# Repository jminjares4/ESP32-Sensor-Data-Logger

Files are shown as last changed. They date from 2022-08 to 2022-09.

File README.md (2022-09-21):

# ESP32-Sensor-Data-Logger

<div align='center'>






</div>

## **Hardware**
sensor data logger gif

## **Mechanical**
housing
* The housing was developed by [Rogelio Marco](https://github.com/RogelioMarco) :gear:.

## **Development**
|Microcontroller|Software|Enviroment|Operating System|
| :---| :---| :---| :---|
|  | |  | |

## **Author**
* [**Jesus Minjares** :zap:](https://github.com/jminjares4)<br>
  * Master of Science in Computer Engineering<br>
 


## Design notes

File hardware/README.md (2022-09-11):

# Hardware

The hardware was developed through [KiCad](https://www.kicad.org) 6.0. 

## **Development**


## **Features**
- [x] USB-C Battery Charger
  - [x] 1.72 A max current charge
  - [x] Load protection
  - [x] Reverse current protection
- [x] Battery voltage reading 
- [x] MicroSD Card
  - [x] ESD Protection
- [x] Real-Time Clock 
  - [x] External power supply (CR2032)
- [x] External UART to flash ESP32 
- [x] I2C and Analog pins
- [x] Onboard status LEDs 
- [x] Testpoint
  - [x] 3.3V
  - [x] Vbat
  - [x] Ground

## **Schematic**
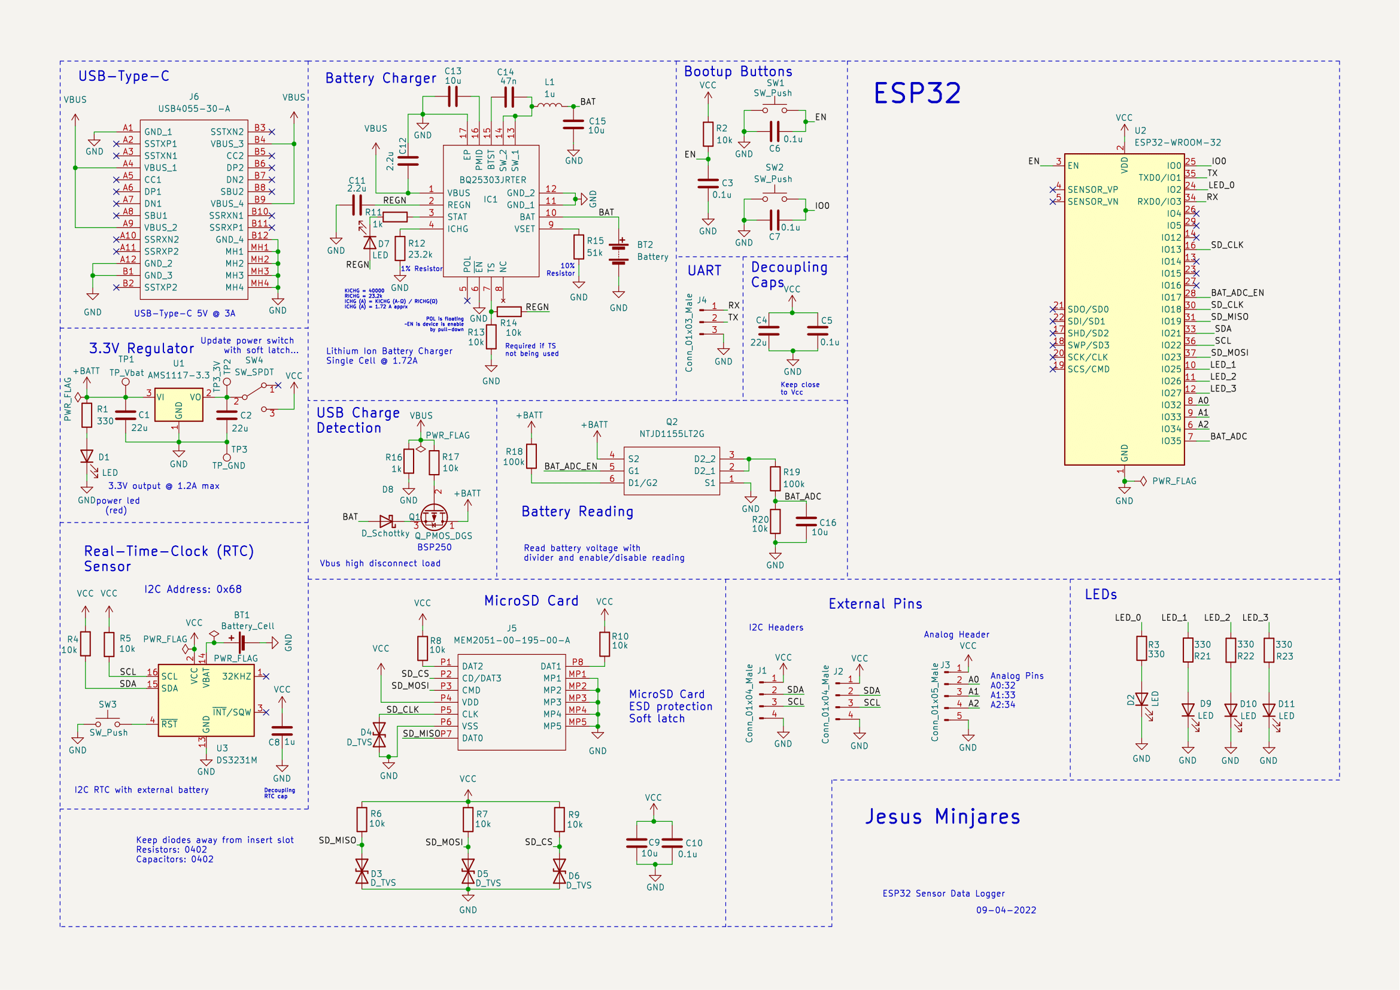
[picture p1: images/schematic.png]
hardware schematic


## **Printed Circuit Board**
### Front View
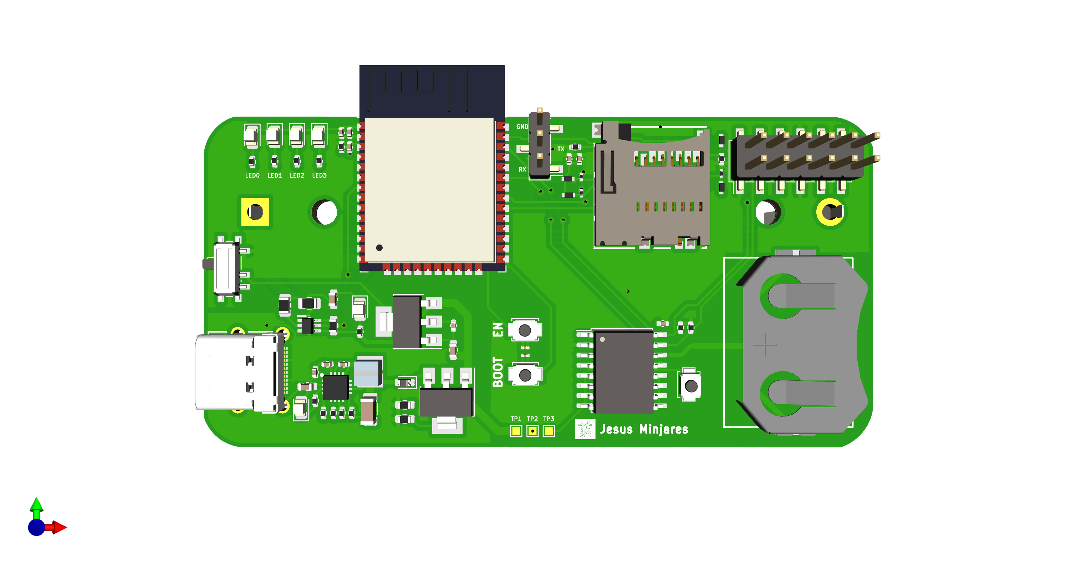
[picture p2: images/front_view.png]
front_view

### Back View
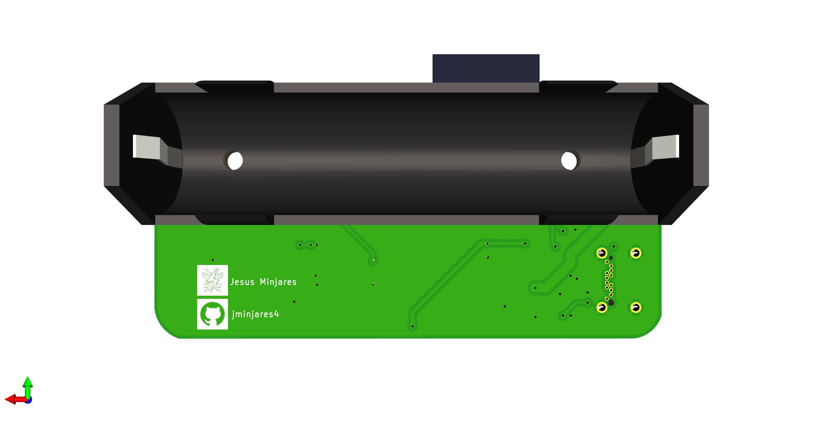
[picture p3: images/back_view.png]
back_view


## **Author**
* [**Jesus Minjares** :zap:](https://github.com/jminjares4)<br>
  * Master of Science in Computer Engineering<br>
 


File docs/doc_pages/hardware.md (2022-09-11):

# Hardware

The hardware was developed through [KiCad](https://www.kicad.org) 6.0. 

## Development


## Features
- [✓] USB-C Battery Charger
  - [✓] 1.72 A max current charge
  - [✓] Load protection
  - [✓] Reverse current protection
- [✓] Battery voltage reading 
- [✓] MicroSD Card
  - [✓] ESD Protection
- [✓] Real-Time Clock 
  - [✓] External power supply (CR2032)
- [✓] External UART to flash ESP32 
- [✓] I2C and Analog pins
- [✓] Onboard status LEDs 
- [✓] Testpoint
  - [✓] 3.3V 
  - [✓] Vbat
  - [✓] Ground

## Schematic
hardware schematic

## Printed Circuit Board
### Front View
front_view
### Back View
back_view

## Author
* [**Jesus Minjares**](https://github.com/jminjares4)<br>
  * Master of Science in Computer Engineering<br>
 


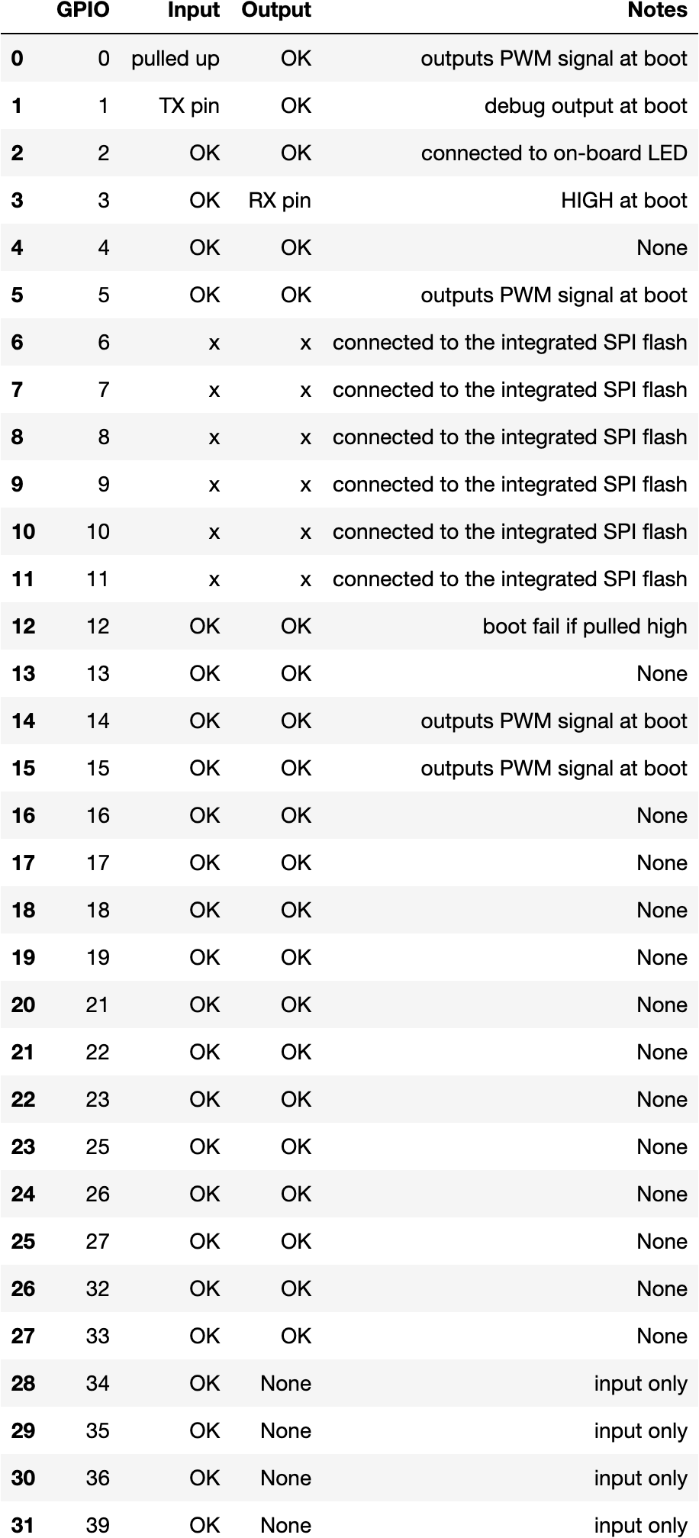
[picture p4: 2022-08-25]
images/esp_pinout.png

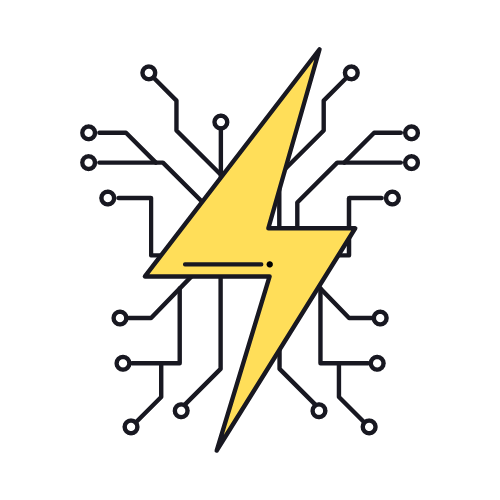
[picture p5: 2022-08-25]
images/jminjares4.png

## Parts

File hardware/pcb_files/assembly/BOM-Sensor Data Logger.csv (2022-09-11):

Comment | Designator | Footprint | LCSC
100k | R18 | R_0603_1608Metric
D_TVS | D3 | TPD1E10B06DPYR
10u | C16 | C_0603_1608Metric
330 | R1 | R_0402_1005Metric
AMS1117-3.3 | U1 | SOT-223-3_TabPin2
10k | R6 | R_0201_0603Metric
D_TVS | D5 | TPD1E10B06DPYR
0.1u | C6 | C_0201_0603Metric
SW_SPDT | SW4 | SW_SPDT_PCM12
LED | D10 | LED_0805_2012Metric
330 | R21 | R_0402_1005Metric
1k | R11 | R_0402_1005Metric
TP_Vbat | TP1 | TestPoint_Pad_1.0x1.0mm
Conn_01x12_Male | J1 | PinHeader_2x06_P2.54mm_Vertical_SMD
SW_Push | SW2 | SW_SPST_B3U-1000P
D_TVS | D4 | TPD1E10B06DPYR
23.2k | R12 | R_0402_1005Metric
10u | C9 | C_0402_1005Metric
10k | R4 | R_0402_1005Metric
10k | R13 | R_0402_1005Metric
USB4055-30-A | J6 | USB405530A
1u | C8 | C_0402_1005Metric
TP3_3V | TP2 | TestPoint_Pad_1.0x1.0mm
0.1u | C5 | C_0402_1005Metric
10k | R7 | R_0201_0603Metric
330 | R23 | R_0402_1005Metric
MEM2051-00-195-00-A | J5 | MEM20510019500A
10k | R8 | R_0402_1005Metric
51k | R15 | R_0402_1005Metric
Battery_Cell | BT1 | 3034
2.2u | C11 | C_0603_1608Metric
SW_Push | SW3 | SW_SPST_B3U-1000P
ESP32-WROOM-32 | U2 | ESP32-WROOM-32
22u | C2 | C_0402_1005Metric
330 | R3 | R_0402_1005Metric
NTJD1155LT2G | Q2 | SOT65P210X110-6N
22u | C4 | C_0402_1005Metric
0.1u | C7 | C_0201_0603Metric
D_TVS | D6 | TPD1E10B06DPYR
10k | R20 | R_0805_2012Metric
LED | D9 | LED_0805_2012Metric
Q_PMOS_DGS | Q1 | SOT-223-3_TabPin2
LED | D7 | LED_0805_2012Metric
1k | R16 | R_0603_1608Metric
BQ25303JRTER | IC1 | QFN50P300X300X80-17N-D
LED | D2 | LED_0805_2012Metric
100k | R19 | R_0805_2012Metric
LED | D11 | LED_0805_2012Metric
0.1u | C10 | C_0402_1005Metric
330 | R22 | R_0402_1005Metric
10u | C15 | C_1206_3216Metric
SW_Push | SW1 | SW_SPST_B3U-1000P
10k | R10 | R_0402_1005Metric
10k | R14 | R_0402_1005Metric
10k | R5 | R_0402_1005Metric
Conn_01x03_Male | J4 | PinHeader_1x03_P2.54mm_Vertical_SMD_Pin1Left
D_Schottky | D8 | D_0603_1608Metric
10u | C13 | C_0402_1005Metric
1u | L1 | INDC3030X200N
LED | D1 | LED_0805_2012Metric
TP_GND | TP3 | TestPoint_Pad_1.0x1.0mm
10k | R17 | R_0603_1608Metric
DS3231M | U3 | SOIC-16W_7.5x10.3mm_P1.27mm
0.1u | C3 | C_0402_1005Metric
22u | C1 | C_0603_1608Metric
2.2u | C12 | C_0402_1005Metric
47n | C14 | C_0402_1005Metric
10k | R9 | R_0201_0603Metric
10k | R2 | R_0402_1005Metric
Battery | BT2 | BatteryHolder_MPD_BH-18650-PC2

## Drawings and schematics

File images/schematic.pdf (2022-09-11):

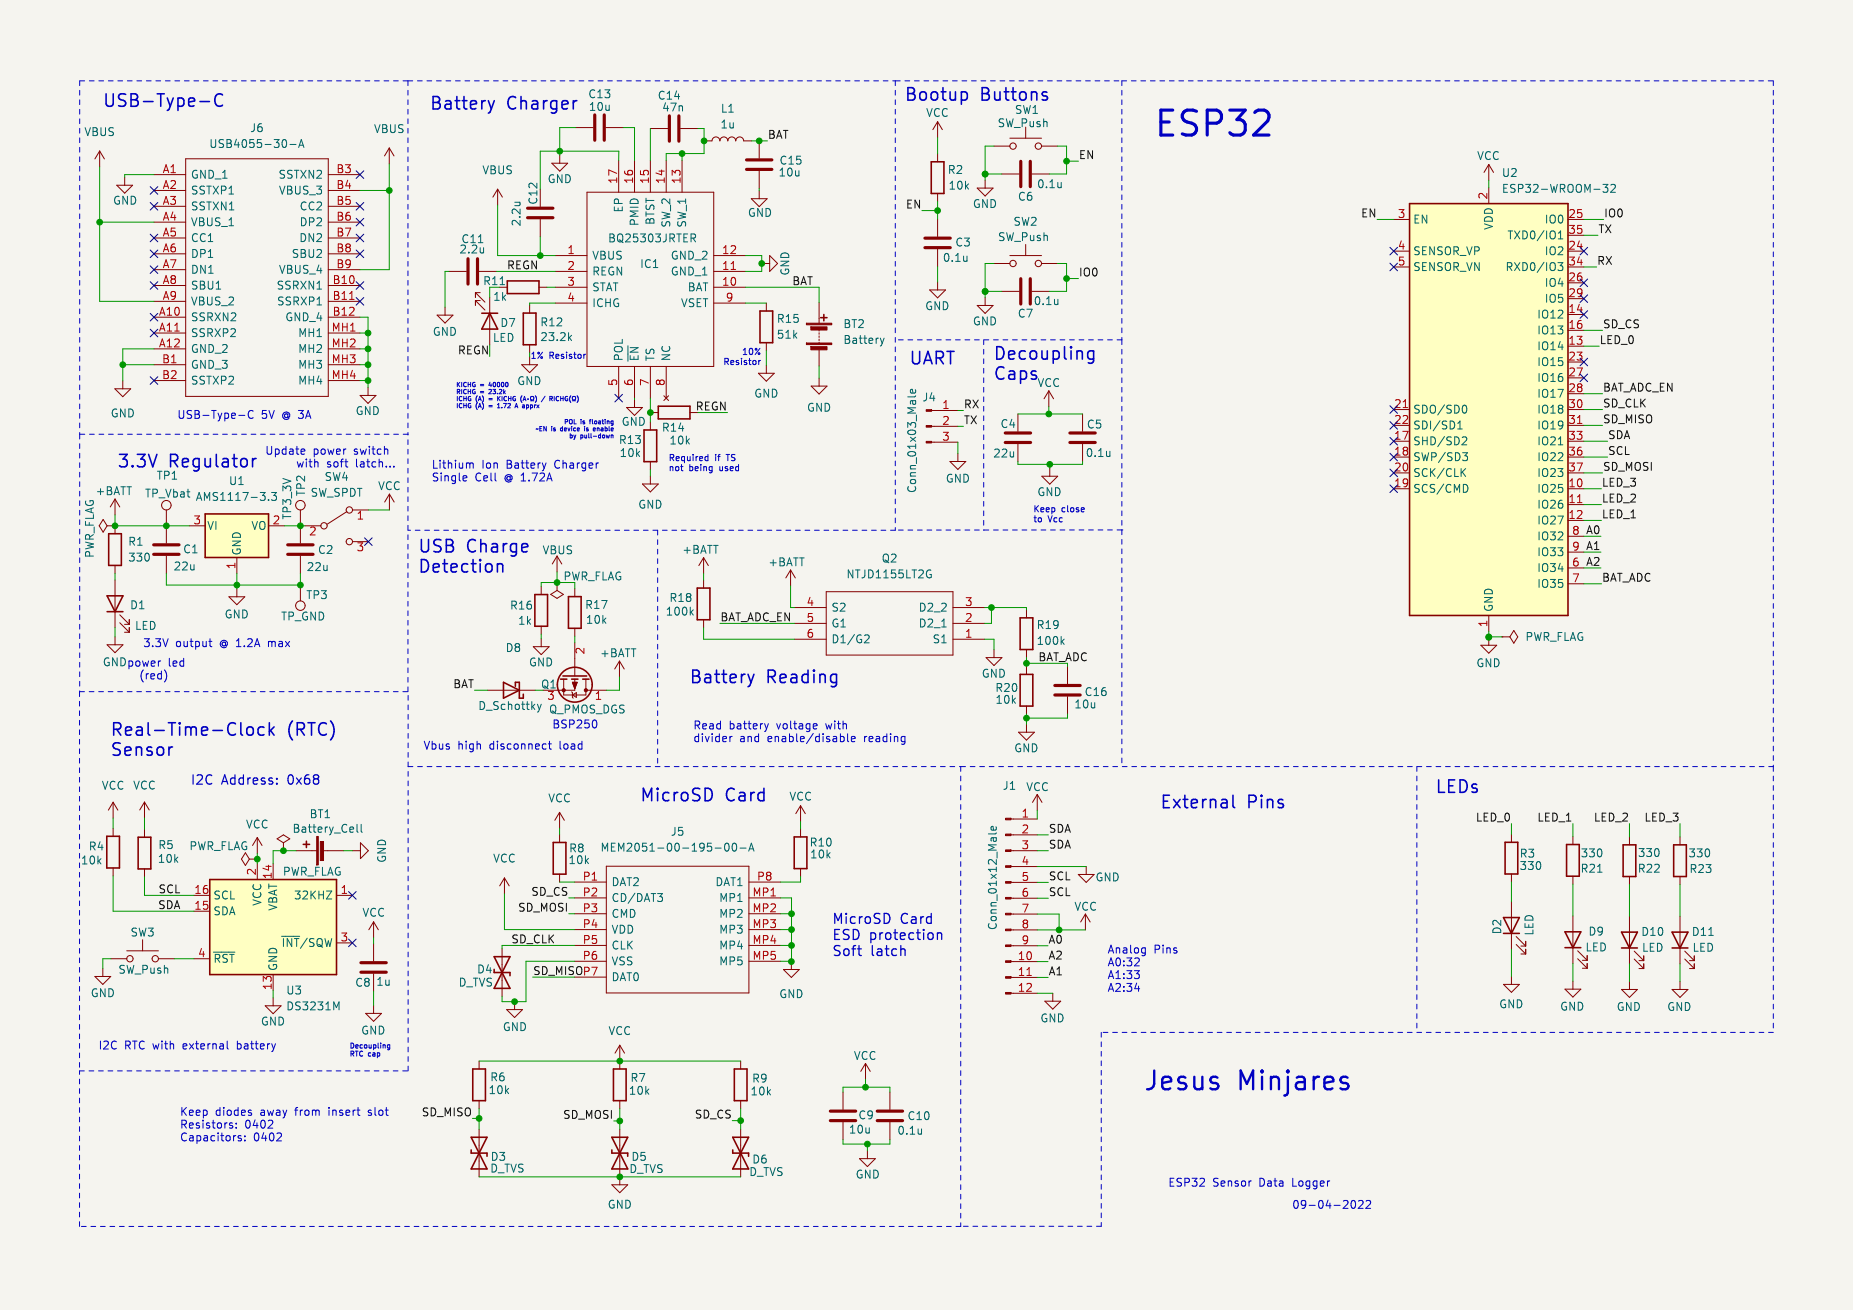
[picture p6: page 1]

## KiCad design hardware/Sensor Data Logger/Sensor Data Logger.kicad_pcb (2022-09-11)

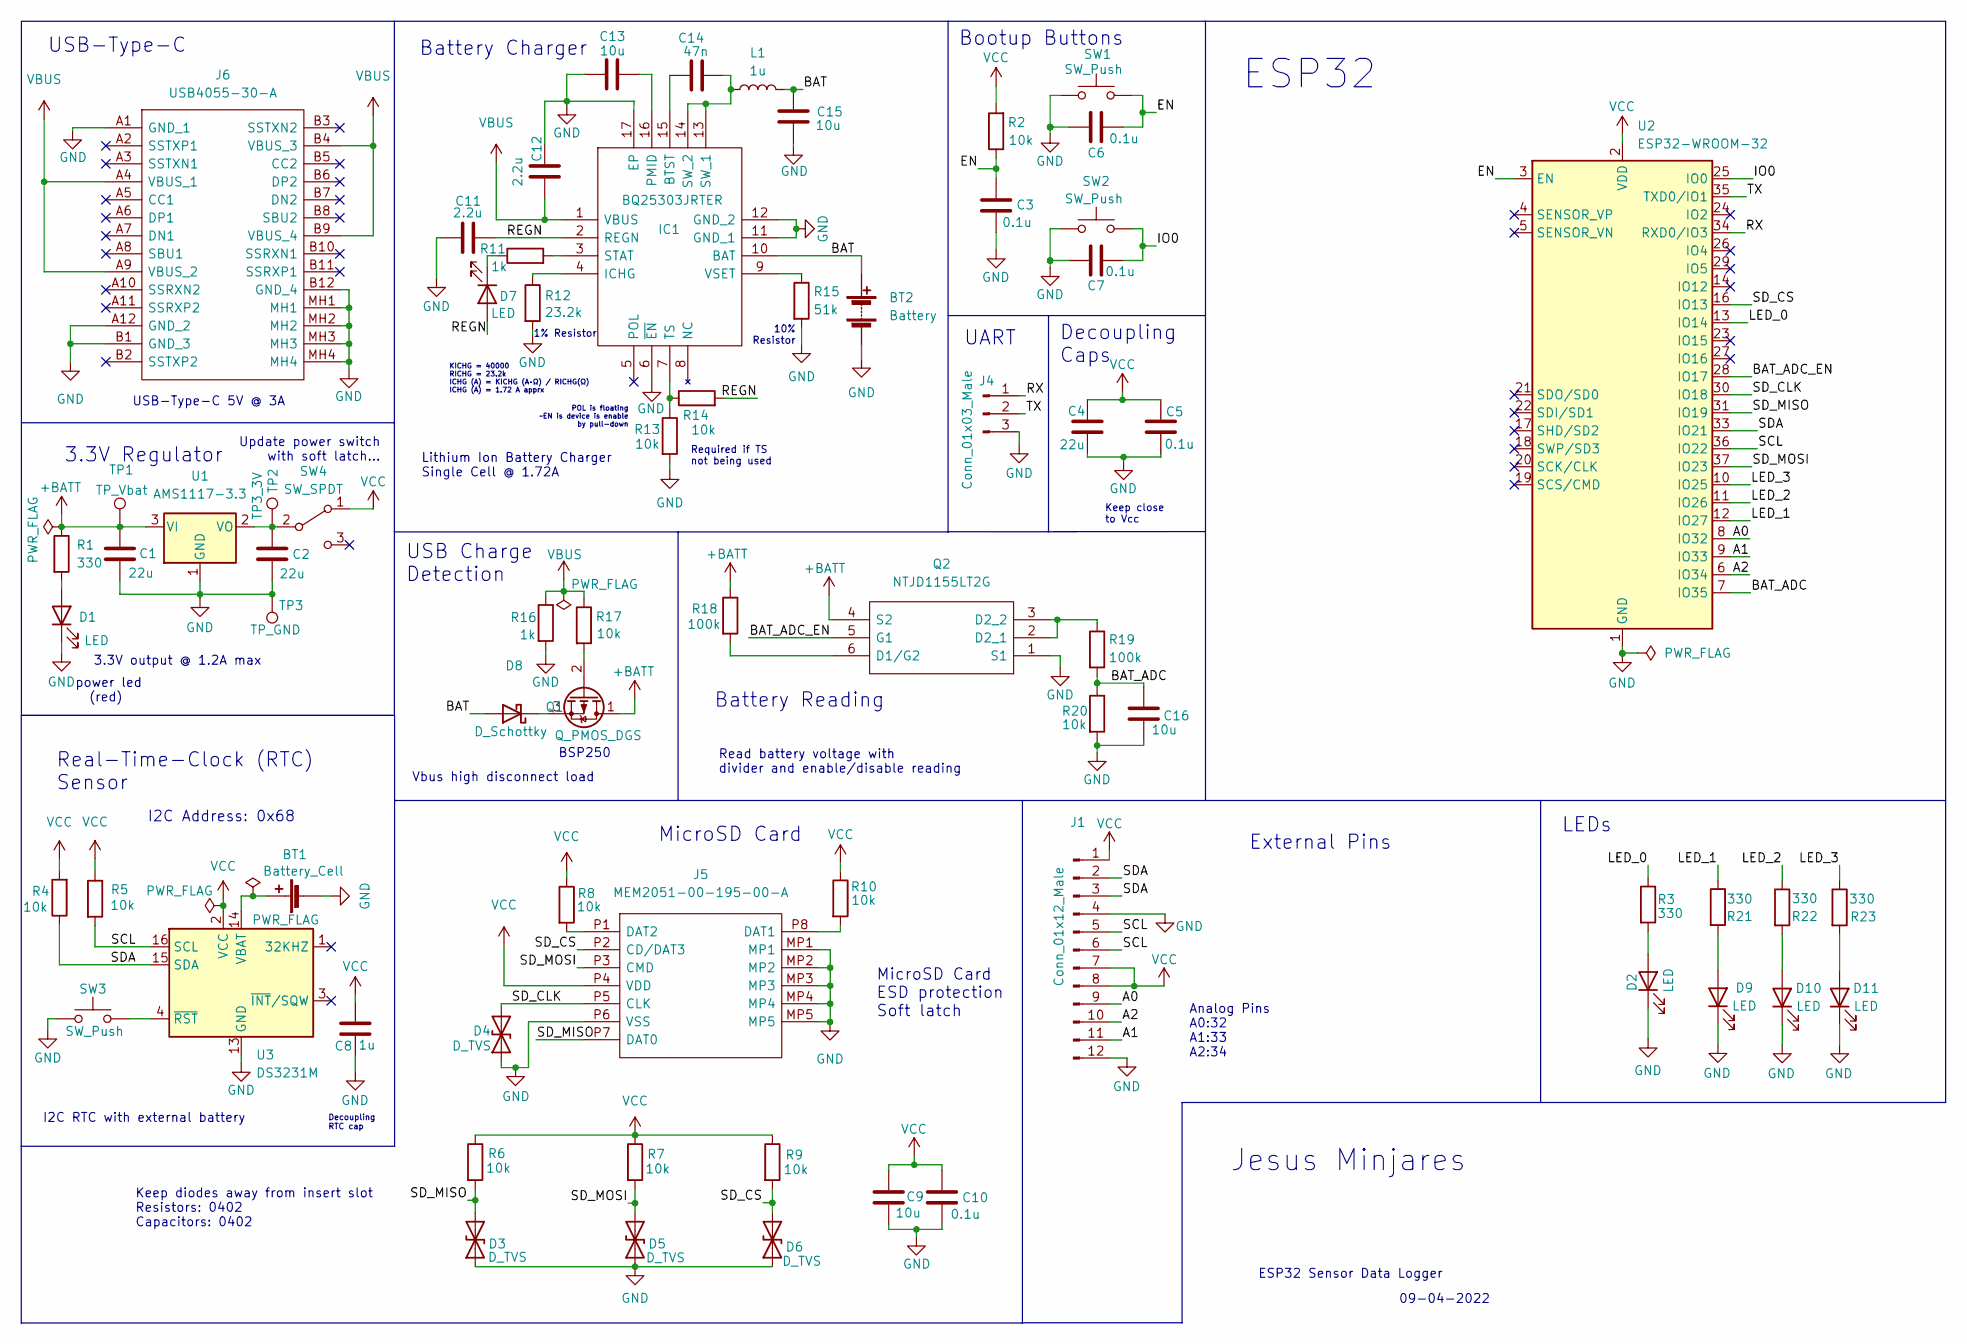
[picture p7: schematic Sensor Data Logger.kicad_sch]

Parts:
BT1: Battery_Cell; 3034
BT2: Battery; BatteryHolder_MPD_BH-18650-PC2
C1: 22u; C_0603_1608Metric
C2, C4: 22u; C_0402_1005Metric
C3, C5, C10: 0.1u; C_0402_1005Metric
C6, C7: 0.1u; C_0201_0603Metric
C8: 1u; C_0402_1005Metric
C9, C13: 10u; C_0402_1005Metric
C11: 2.2u; C_0603_1608Metric
C12: 2.2u; C_0402_1005Metric
C14: 47n; C_0402_1005Metric
C15: 10u; C_1206_3216Metric
C16: 10u; C_0603_1608Metric
D1, D2, D7, D9, D10, D11: LED; LED_0805_2012Metric
D3, D4, D5, D6: D_TVS; TPD1E10B06DPYR
D8: D_Schottky; D_0603_1608Metric
IC1: BQ25303JRTER; QFN50P300X300X80-17N-D; Manufacturer_Part_Number BQ25303JRTER; Mouser Part Number 595-BQ25303JRTER
J1: Conn_01x12_Male; PinHeader_2x06_P2.54mm_Vertical_SMD
J4: Conn_01x03_Male; PinHeader_1x03_P2.54mm_Vertical_SMD_Pin1Left
J5: MEM2051-00-195-00-A; MEM20510019500A; Manufacturer_Part_Number MEM2051-00-195-00-A; Mouser Part Number 640-MEM20510019500A
J6: USB4055-30-A; USB405530A; Manufacturer_Part_Number USB4055-30-A; Mouser Part Number 640-USB4055-30-A
L1: 1u; INDC3030X200N
Q1: Q_PMOS_DGS; SOT-223-3_TabPin2
Q2: NTJD1155LT2G; SOT65P210X110-6N; Manufacturer_Part_Number NTJD1155LT2G; Mouser Part Number 863-NTJD1155LT2G
R1, R3, R21, R22, R23: 330; R_0402_1005Metric
R2, R4, R5, R8, R10, R13, R14: 10k; R_0402_1005Metric
R6, R7, R9: 10k; R_0201_0603Metric
R11: 1k; R_0402_1005Metric
R12: 23.2k; R_0402_1005Metric
R15: 51k; R_0402_1005Metric
R16: 1k; R_0603_1608Metric
R17: 10k; R_0603_1608Metric
R18: 100k; R_0603_1608Metric
R19: 100k; R_0805_2012Metric
R20: 10k; R_0805_2012Metric
SW1, SW2, SW3: SW_Push; SW_SPST_B3U-1000P
SW4: SW_SPDT; SW_SPDT_PCM12
TP1: TP_Vbat; TestPoint_Pad_1.0x1.0mm
TP2: TP3_3V; TestPoint_Pad_1.0x1.0mm
TP3: TP_GND; TestPoint_Pad_1.0x1.0mm
U1: AMS1117-3.3; SOT-223-3_TabPin2
U2: ESP32-WROOM-32
U3: DS3231M; SOIC-16W_7.5x10.3mm_P1.27mm

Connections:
+BATT: C1.1, Q1.1 (D), Q2.4 (S2), R1.1, R18.1, TP1.1, U1.3 (VI)
/A0: J1.9, U2.8 (IO32)
/A1: J1.11, U2.9 (IO33)
/A2: J1.10, U2.6 (IO34)
/BAT: BT2.1 (+), C15.1, D8.2 (A), IC1.10 (BAT), L1.2
/BAT_ADC: C16.1, R19.2, R20.1, U2.7 (IO35)
/BAT_ADC_EN: Q2.5 (G1), U2.28 (IO17)
/EN: C3.1, C6.2, R2.1, SW1.2, U2.3 (EN)
/IO0: C7.2, SW2.2, U2.25 (IO0)
/LED_0: R3.1, U2.13 (IO14)
/LED_1: R21.1, U2.12 (IO27)
/LED_2: R22.1, U2.11 (IO26)
/LED_3: R23.1, U2.10 (IO25)
/REGN: C11.2, D7.2 (A), IC1.2 (REGN), R14.2
/RX: J4.1, U2.34 (RXD0/IO3)
/SCL: J1.5, J1.6, R5.2, U2.36 (IO22), U3.16 (SCL)
/SDA: J1.2, J1.3, R4.1, U2.33 (IO21), U3.15 (SDA)
/SD_CLK: D4.2 (A2), J5.P5 (CLK), U2.30 (IO18)
/SD_CS: D6.2 (A2), J5.P2 (CD/DAT3), R9.2, U2.16 (IO13)
/SD_MISO: D3.2 (A2), J5.P7 (DAT0), R6.2, U2.31 (IO19)
/SD_MOSI: D5.2 (A2), J5.P3 (CMD), R7.2, U2.37 (IO23)
/TX: J4.2, U2.35 (TXD0/IO1)
unnamed: C2.1, SW4.2 (B), TP2.1, U1.2 (VO)
unnamed: C6.1, SW1.1
unnamed: C7.1, SW2.1
unnamed: C13.1, IC1.16 (PMID)
unnamed: C14.1, IC1.15 (BTST)
unnamed: C14.2, IC1.13 (SW_1), IC1.14 (SW_2), L1.1
unnamed: D1.2 (A), R1.2
unnamed: D2.2 (A), R3.2
unnamed: D7.1 (K), R11.1
unnamed: D8.1 (K), Q1.3 (S)
unnamed: D9.2 (A), R21.2
unnamed: D10.2 (A), R22.2
unnamed: D11.2 (A), R23.2
unnamed: IC1.3 (STAT), R11.2
unnamed: IC1.4 (ICHG), R12.1
unnamed: IC1.7 (TS), R13.1, R14.1
unnamed: IC1.9 (VSET), R15.1
unnamed: J5.MP1, J5.MP2, J5.MP3, J5.MP4, J5.MP5
unnamed: J5.P1 (DAT2), R8.2
unnamed: J5.P8 (DAT1), R10.2
unnamed: Q1.2 (G), R17.2
unnamed: Q2.2 (D2_1), Q2.3 (D2_2), R19.1
unnamed: Q2.6 (D1/G2), R18.2
unnamed: SW3.2, U3.4 (~RST)
VBUS: C12.2, IC1.1 (VBUS), J6.A4 (VBUS_1), J6.A9 (VBUS_2), J6.B4 (VBUS_3), J6.B9 (VBUS_4), R16.1, R17.1
VCC: C4.1, C5.1, C8.1, C9.1, C10.1, J1.1, J1.7, J1.8, J5.P4 (VDD), R2.2, R4.2, R5.1, R6.1, R7.1, R8.1, R9.1, R10.1, SW4.1 (A), U2.2 (VDD), U3.2 (VCC)

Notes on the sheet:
Keep diodes away from insert slot Resistors: 0402 Capacitors: 0402
MicroSD Card
ESP32 Sensor Data Logger
Required if TS not being used
Vbus high disconnect load
Update power switch with soft latch...
UART
POL is floating ~EN is device is enable by pull-down
3.3V output @ 1.2A max
ESP32
BSP250
Jesus Minjares
10% Resistor
USB-Type-C 5V @ 3A
External Pins
USB-Type-C
Read battery voltage with divider and enable/disable reading
1% Resistor
Decoupling Caps
3.3V Regulator
LEDs
Keep close to Vcc
I2C RTC with external battery
KICHG = 40000 RICHG = 23.2k ICHG (A) = KICHG (A·Ω) / RICHG(Ω) ICHG (A) = 1.72 A apprx
Bootup Buttons
09-04-2022
Lithium Ion Battery Charger Single Cell @ 1.72A
Battery Reading
Real-Time-Clock (RTC) Sensor
I2C Address: 0x68
Decoupling RTC cap
Analog Pins A0:32 A1:33 A2:34
Battery Charger
MicroSD Card ESD protection Soft latch
power led (red)
USB Charge Detection

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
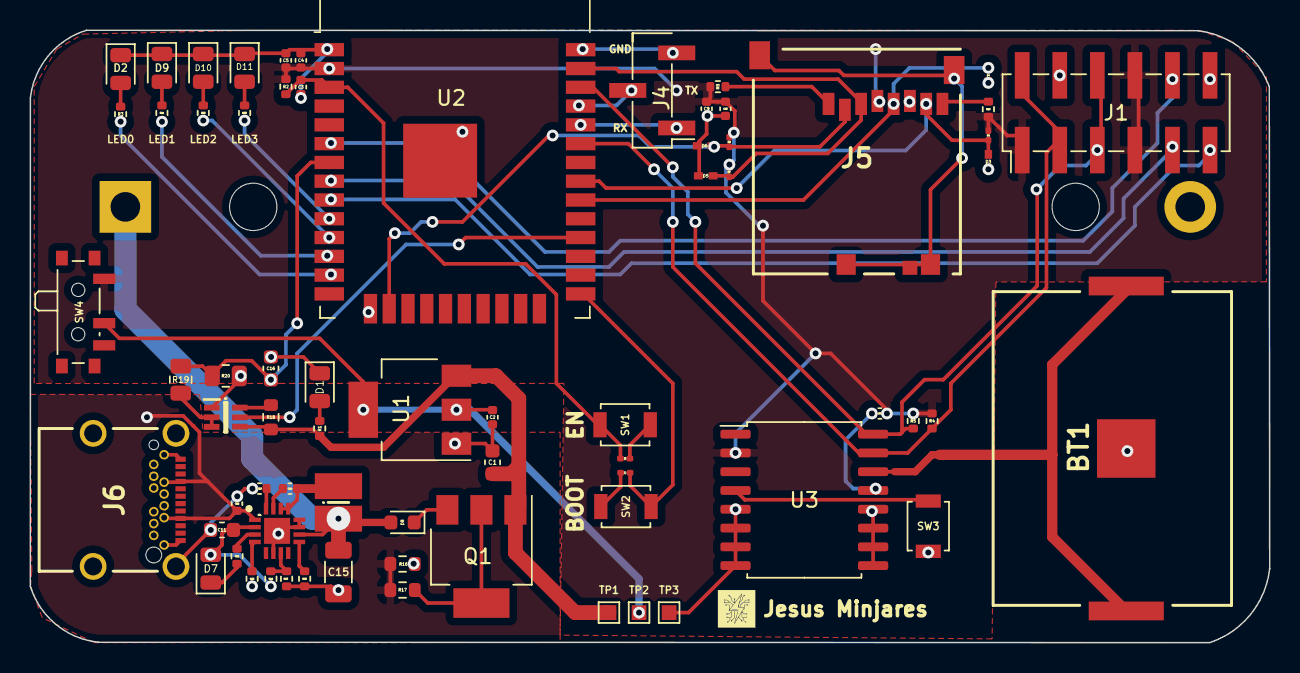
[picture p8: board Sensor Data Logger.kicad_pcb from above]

Board: 2 copper layers, 83.8 x 41.4 mm, 70 parts (1 on the bottom side), 50 nets.

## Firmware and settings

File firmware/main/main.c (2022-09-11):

#include <stdio.h>
#include <string.h>
#include "freertos/FreeRTOS.h"
#include "freertos/task.h"
#include "driver/gpio.h"
#include "freertos/queue.h"

/* Drivers */
#include "button/button.h"
#include "lcd/esp_lcd.h"
#include "led/led.h"
#include "battery/battery.h"

/* I2C drivers */
#include "bmp180.h"
#include "ds3231.h"
#include <inttypes.h>

/* SD Card */
#include <sys/unistd.h>
#include <sys/stat.h>
#include "esp_vfs_fat.h"
#include "sdmmc_cmd.h"

/* Battery reading */
#include "driver/adc.h"

/* ESP-IDF version */
#include "esp_idf_version.h"
/* Timer */
#include "esp_timer.h"

/* Custom headers */
#include "sensor/sensor.h"
#include "sdcard/sd_card.h"
#include "timer/timer.h"

#define ONBOARD_LED 2

QueueHandle_t pressureSensorQueue;
QueueHandle_t realTimeClockQueue;

/* Notification Handle */
static TaskHandle_t sensorHandle = NULL;
static TaskHandle_t rtcHandle = NULL;
static TaskHandle_t batteryHandle = NULL;

void lcdTask(void *pvParameters)
{
   /* Create LCD object */
   lcd_t lcd;

   /* Set LCD to custom pinout */
   gpio_num_t data[4] = {19, 18, 17, 16}; /* Data pins */
   gpio_num_t en = 27;                    /* Enable pin */
   gpio_num_t regSel = 26;                /* Register Select pin */

   lcdCtor(&lcd, data, en, regSel);

   /* Initialize LCD */
   lcdInit(&lcd);
   /* Clear previous data */
   lcdClear(&lcd);

   /* Set text */
   lcdSetText(&lcd, "Custom ESP LCD", 0, 0);

   /* Variable */
   int count = 0; /* count */

   while (1)
   {
      /* Set custom text */
      lcdSetText(&lcd, "Count: ", 0, 1);
      lcdSetInt(&lcd, count, 8, 1);
      count++;                               /* Increment count */
      vTaskDelay(1000 / portTICK_PERIOD_MS); /* 1 second delay */
   }
}

void bmp180Task(void *pvParameters)
{
   /* Create bmp180 device */
   bmp180_dev_t dev;
   /* Clear memory */
   memset(&dev, 0, sizeof(bmp180_dev_t));

   /* I2C pins */
   gpio_num_t i2c_sda = 21;
   gpio_num_t i2c_scl = 22;

   ESP_ERROR_CHECK(bmp180_init_desc(&dev, 0, i2c_sda, i2c_scl));
   ESP_ERROR_CHECK(bmp180_init(&dev));

   data_t bmp180Sensor;
   bmp180Sensor.event = BMP180_SENSOR;

   while (1)
   {
      /* Wait for nofitication */
      uint32_t count = ulTaskNotifyTake(pdTRUE, portMAX_DELAY);
      /* Display re */
      printf("BMP180 count: %lu\n", (unsigned long)count);

      float temp;
      uint32_t pressure;

      esp_err_t res = bmp180_measure(&dev, &temp, &pressure, BMP180_MODE_STANDARD);
      if (res != ESP_OK)
         printf("Could not measure: %d\n", res);
      else
      {
         /* float is used in printf(). you need non-default configuration in
          * sdkconfig for ESP8266, which is enabled by default for this
          * example. see sdkconfig.defaults.esp8266
          */
         // printf("Temperature: %.2f degrees Celsius; Pressure: %" PRIu32 " Pa\n", temp, pressure);

         bmp180Sensor.data0 = (void *)&temp;
         bmp180Sensor.data1 = (void *)&pressure;

         /* Send queue data */
         xQueueSendToBack(pressureSensorQueue, &bmp180Sensor, 0);
      }

      vTaskDelay(pdMS_TO_TICKS(500));
   }
}

void rtcTask(void *pvParameters)
{

   /* Allocate memory */
   i2c_dev_t dev;
   memset(&dev, 0, sizeof(i2c_dev_t));

   /* Select i2c pins */
   gpio_num_t i2c_sda = 21;
   gpio_num_t i2c_scl = 22;

   /* Initialize device */
   ESP_ERROR_CHECK(ds3231_init_desc(&dev, 0, i2c_sda, i2c_scl));

   struct tm time = {
       .tm_year = 122, // since 1900 (2016 - 1900)
       .tm_mon = 10,   // 0-based
       .tm_mday = 26,
       .tm_hour = 19,
       .tm_min = 7,
       .tm_sec = 0};
   ESP_ERROR_CHECK(ds3231_set_time(&dev, &time));

   data_t ds3231Sensor;
   ds3231Sensor.event = DS3231_SENSOR;

   while (1)
   {

      /* Wait for nofitication */
      uint32_t count = ulTaskNotifyTake(pdTRUE, portMAX_DELAY);
      /* Display re */
      printf("D3231 count: %lu\n", (unsigned long)count);

      float temp;

      // vTaskDelay(1000 / portTICK_PERIOD_MS);

      if (ds3231_get_temp_float(&dev, &temp) != ESP_OK)
      {
         printf("Could not get temperature\n");
         continue;
      }

      if (ds3231_get_time(&dev, &time) != ESP_OK)
      {
         printf("Could not get time\n");
         continue;
      }

      /* float is used in printf(). you need non-default configuration in
       * sdkconfig for ESP8266, which is enabled by default for this
       * example. see sdkconfig.defaults.esp8266
       */
      // printf("%04d-%02d-%02d %02d:%02d:%02d, %.2f deg Cel\n", time.tm_year + 1900 /*Add 1900 for better readability*/, time.tm_mon + 1,
      //        time.tm_mday, time.tm_hour, time.tm_min, time.tm_sec, temp);

      ds3231Sensor.data0 = (void *)&time;

      xQueueSendToBack(realTimeClockQueue, &ds3231Sensor, 0);
   }
}

void sdcardTask(void *pvParameters)
{
   esp_err_t ret;

   // Options for mounting the filesystem.
   // If format_if_mount_failed is set to true, SD card will be partitioned and
   // formatted in case when mounting fails.
   esp_vfs_fat_sdmmc_mount_config_t mount_config = {
#ifdef CONFIG_EXAMPLE_FORMAT_IF_MOUNT_FAILED
       .format_if_mount_failed = true,
#else
       .format_if_mount_failed = false,
#endif // EXAMPLE_FORMAT_IF_MOUNT_FAILED
       .max_files = 5,
       .allocation_unit_size = 16 * 1024};
   sdmmc_card_t *card;
   const char mount_point[] = MOUNT_POINT;
   ESP_LOGI(SD_CARD_TAG, "Initializing SD card");

   // Use settings defined above to initialize SD card and mount FAT filesystem.
   // Note: esp_vfs_fat_sdmmc/sdspi_mount is all-in-one convenience functions.
   // Please check its source code and implement error recovery when developing
   // production applications.
   ESP_LOGI(SD_CARD_TAG, "Using SPI peripheral");

   sdmmc_host_t host = SDSPI_HOST_DEFAULT();
   spi_bus_config_t bus_cfg = {
       .mosi_io_num = PIN_NUM_MOSI,
       .miso_io_num = PIN_NUM_MISO,
       .sclk_io_num = PIN_NUM_CLK,
       .quadwp_io_num = -1,
       .quadhd_io_num = -1,
       .max_transfer_sz = 4000,
   };
#if ESP_IDF_VERSION >= ESP_IDF_VERSION_VAL(5, 0, 0)
   ret = spi_bus_initialize(host.slot, &bus_cfg, SDSPI_DEFAULT_DMA);
#else
   ret = spi_bus_initialize(host.slot, &bus_cfg, SDSPI_DEFAULT_HOST);
#endif
   if (ret != ESP_OK)
   {
      ESP_LOGE(SD_CARD_TAG, "Failed to initialize bus.");
      return;
   }

   // This initializes the slot without card detect (CD) and write protect (WP) signals.
   // Modify slot_config.gpio_cd and slot_config.gpio_wp if your board has these signals.
   sdspi_device_config_t slot_config = SDSPI_DEVICE_CONFIG_DEFAULT();
   slot_config.gpio_cs = PIN_NUM_CS;
   slot_config.host_id = host.slot;

   ESP_LOGI(SD_CARD_TAG, "Mounting filesystem");
   ret = esp_vfs_fat_sdspi_mount(mount_point, &host, &slot_config, &mount_config, &card);

   if (ret != ESP_OK)
   {
      if (ret == ESP_FAIL)
      {
         ESP_LOGE(SD_CARD_TAG, "Failed to mount filesystem. "
                               "If you want the card to be formatted, set the CONFIG_EXAMPLE_FORMAT_IF_MOUNT_FAILED menuconfig option.");
      }
      else
      {
         ESP_LOGE(SD_CARD_TAG, "Failed to initialize the card (%s). "
                               "Make sure SD card lines have pull-up resistors in place.",
                  esp_err_to_name(ret));
      }
      return;
   }
   ESP_LOGI(SD_CARD_TAG, "Filesystem mounted");

   // Card has been initialized, print its properties
   sdmmc_card_print_info(stdout, card);

   // Use POSIX and C standard library functions to work with files.

   // First create a file.
   const char *file_hello = MOUNT_POINT "/test.txt";

   ESP_LOGI(SD_CARD_TAG, "Opening file %s", file_hello);
   FILE *f = fopen(file_hello, "w");
   if (f == NULL)
   {
      ESP_LOGE(SD_CARD_TAG, "Failed to open file for writing");
      return;
   }
   fprintf(f, "Hello %s!\n", card->cid.name);
   printf("Hello  %s!\n", card->cid.name);
   fclose(f);
   ESP_LOGI(SD_CARD_TAG, "File written");

   const char *file_foo = MOUNT_POINT "/foo.txt";

   // Check if destination file exists before renaming
   struct stat st;
   if (stat(file_foo, &st) == 0)
   {
      // Delete it if it exists
      unlink(file_foo);
   }

   // Rename original file
   ESP_LOGI(SD_CARD_TAG, "Renaming file %s to %s", file_hello, file_foo);
   if (rename(file_hello, file_foo) != 0)
   {
      ESP_LOGE(SD_CARD_TAG, "Rename failed");
      return;
   }

   // Open renamed file for reading
   ESP_LOGI(SD_CARD_TAG, "Reading file %s", file_foo);
   f = fopen(file_foo, "r");
   if (f == NULL)
   {
      ESP_LOGE(SD_CARD_TAG, "Failed to open file for reading");
      return;
   }

   // Read a line from file
   char line[64];
   fgets(line, sizeof(line), f);
   fclose(f);

   // Strip newline
   char *pos = strchr(line, '\n');
   if (pos)
   {
      *pos = '\0';
   }
   ESP_LOGI(SD_CARD_TAG, "Read from file: '%s'", line);
   printf("Data: %s\n", line);

   // All done, unmount partition and disable SPI peripheral
   esp_vfs_fat_sdcard_unmount(mount_point, card);
   ESP_LOGI(SD_CARD_TAG, "Card unmounted");

   // deinitialize the bus after all devices are removed
   spi_bus_free(host.slot);

   while (1)
   {
      vTaskDelay(100);
   }
}

void timer_callback(void *arg)
{
   /* Send message */
   printf("Timer was trigger!!!\n");
   /* store previous state of gpio */
   static bool on;
   /* toggle state */
   on = !on;
   /* Set gpio level */
   gpio_set_level(ONBOARD_LED, on);

   /* Give task handle */
   xTaskNotifyGive(sensorHandle);
   xTaskNotifyGive(rtcHandle);
}

void timerTask(void *pvParameters)
{
#if ESP_IDF_VERSION >= ESP_IDF_VERSION_VAL(5, 0, 0)
   esp_rom_gpio_pad_select_gpio(ONBOARD_LED);
#else
   gpio_pad_select_gpio(ONBOARD_LED);
#endif
   gpio_set_direction(ONBOARD_LED, GPIO_MODE_OUTPUT);
   gpio_set_level(ONBOARD_LED, 0);

   /* Set timer arguments */
   esp_timer_create_args_t timer_args = {
       .callback = timer_callback,
       .arg = NULL,
       .dispatch_method = ESP_TIMER_TASK,
       .name = "Sensor Timer Trigger",
       .skip_unhandled_events = false,
   };
   /* Create timer handle */
   esp_timer_handle_t timer_handle;
   /* Create an instance of timer */
   esp_timer_create(&timer_args, &timer_handle);

   /* Set period */
   uint64_t period = ONE_SECOND;

   /* Start periodic timer */
   esp_timer_start_periodic(timer_handle, period);

   while (1)
   {
      vTaskDelay(100); /* avoid WDT trigger */
   }
}

void dataTask(void *pvParameters)
{

   data_t sensor[2];
   /*RTC sensor data */
   struct tm time;
   /* Pressure sensor data */
   float temp = 0.0;
   uint32_t pressure = 0;

   while (1)
   {
      /* Wait for both queues */
      if (xQueueReceive(realTimeClockQueue, &sensor[0], (TickType_t)100) == pdPASS &&
          xQueueReceive(pressureSensorQueue, &sensor[1], (TickType_t)100) == pdPASS)
      {
         /* Verify that sensor 0 is the DS3231 */
         if (sensor[0].event == DS3231_SENSOR)
         {
            /* Store data into time */
            time = *(struct tm *)sensor[0].data0;
         }
         /* Verify that sensor 1 is the BMP180 */
         if (sensor[1].event == BMP180_SENSOR)
         {
            /* Store data into temp & pressure */
            temp = *(float *)sensor[1].data0;
            pressure = *(uint32_t *)sensor[1].data1;
         }

         /* Display time */
         printf("RTC: %04d-%02d-%02d %02d:%02d:%02d\n", time.tm_year + 1900 /*Add 1900 for better readability*/, time.tm_mon + 1,
                time.tm_mday, time.tm_hour, time.tm_min, time.tm_sec);
         /* Display temp & pressure */
         printf("BMP180: Temperature: %.2f degrees Celsius; Pressure: %" PRIu32 " Pa\n", temp, pressure);
      }
      else
      {
         vTaskDelay(100); /* avoid WDT */
      }
   }
}

void batteryTask(void *pvParameters)
{
   /* Create an instance of battery object */
   battery_t battery;

   /* Set battery to default configuration */
   battery_default(&battery);

   /* Intialize battery */
   battery_init(&battery);

   /* Disable battery */
   battery_disable(&battery);

   /* 250 ms delay */
   vTaskDelay(250 / portTICK_PERIOD_MS);

   /* Enable battery */
   battery_enable(&battery);

   while (1)
   {
      /* Get voltage reading */
      int value = battery_read(&battery);
      printf("Value: %d\tBattery: %d\n", value, battery.value);

      uint16_t percentage = battery_percentage(&battery);
      printf("Percentage: %d\n", percentage);

      vTaskDelay(1000 / portTICK_PERIOD_MS);
   }
}

void app_main(void)
{
   /* Initialize Queue*/
   pressureSensorQueue = xQueueCreate(QUEUE_SIZE, sizeof(data_t));
   realTimeClockQueue = xQueueCreate(QUEUE_SIZE, sizeof(data_t));

   /* Create mutex for i2c devices */
   ESP_ERROR_CHECK(i2cdev_init());
   /* Create SD Card task */
   xTaskCreate(&sdcardTask, "SDCARD Task", 4096, NULL, 12, NULL);
   /* Create LCD task */
   xTaskCreate(&lcdTask, "LCD task", 2048, NULL, 3, NULL);
   /* Create bmp180 task */
   xTaskCreate(&bmp180Task, "BMP180 Task", 1920, NULL, 4, &sensorHandle);
   /* Create RTC task */
   xTaskCreate(&rtcTask, "RTC Task", 2048, NULL, 4, &rtcHandle);
   /* Create timer task @ 1 second trigger  */
   xTaskCreate(&timerTask, "ESP Timer Task", 2048, NULL, 10, NULL);

   /* Create temp task to display queue data*/
   xTaskCreate(&dataTask, "Queue Data Task", 2048, NULL, 10, NULL);

   /* Create battery reading task */
   xTaskCreate(&batteryTask, "Battery reading task", 1024, NULL, 10, &batteryHandle);
}

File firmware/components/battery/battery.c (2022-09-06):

/**
 * @file battery.c
 * @author Jesus Minjares (https://github.com/jminjares4)
 * @brief Battery driver
 * @version 0.1
 * @date 2022-09-01
 *
 * @copyright Copyright (c) 2022
 *
 */

#include "battery.h"
#include "esp_idf_version.h"

#define ADC_CHANNEL_DEFAULT ADC1_CHANNEL_7       /*!< ADC channel default */
#define ADC_WIDTH_DEFAULT ADC_WIDTH_BIT_12       /*!< ADC width default  */
#define ADC_ATTENUATION_DEFAULT ADC_ATTEN_DB_2_5 /*!< ADC attentuation default */
#define BATTERY_ENABLE_DEFAULT 17                /*!< Battery gpio default  */

/* Voltage divider */
#define R2 100
#define R3 10

/* Battery max and min voltage */
#define V_MAX 4200
#define V_MIN 3300

/**
 * @brief Voltage output from divider
 *
 * @param vin   voltage input
 * @return int  voltage
 */
static int voltage_divider(int vin)
{
    return (vin * R3) / (R2 + R3);
}

/**
 * @brief Voltage to adc reading
 *
 * @param value     voltage
 * @param battery   pointer to a const battery object
 * @return int      adc value
 */
static int voltage_to_adc(int value, battery_t *const battery)
{
    /* Get voltage reference from attenuation */
    int vref;
    switch (battery->attenuation)
    {
    case ADC_ATTEN_DB_0:
        vref = 800;
        break;
    case ADC_ATTEN_DB_2_5:
        vref = 1100;
        break;
    case ADC_ATTEN_DB_6:
        vref = 1350;
        break;
    case ADC_ATTEN_DB_11:
        vref = 2600;
        break;
    default:
        vref = 1100;
    }
    /* Get bit resolution from width */
    int bit_res;
    switch (battery->width)
    {
    case ADC_WIDTH_BIT_9:
        bit_res = 512;
        break;
    case ADC_WIDTH_BIT_10:
        bit_res = 1024;
        break;
    case ADC_WIDTH_BIT_11:
        bit_res = 2048;
        break;
    case ADC_WIDTH_BIT_12:
        bit_res = 4096;
        break;
    default:
        bit_res = 4096;
    }

    /* Get conversion: raw adc to voltage */
    return ((vref * value) / bit_res);
}

/**
 * @brief Battery percentage
 *
 * @param battery   pointer to a const battery object
 * @return int percent value
 */
int battery_percentage(battery_t *const battery)
{
    /* Convert battery voltage min to adc */
    int battery_min = voltage_to_adc(voltage_divider(V_MIN), battery);
    /* Convert battery voltage max to adc */
    int battery_max = voltage_to_adc(voltage_divider(V_MAX), battery);

    /* Get battery percentage */
    int battery_percentage = 100 * (battery->value - battery_min) / (battery_max - battery_min);

    /* Set boundaries */
    if (battery_percentage < 0)
        battery_percentage = 0;
    if (battery_percentage > 100)
        battery_percentage = 100;

    return battery_percentage;
}

/**
 * @brief Battery object constructor
 *
 * @param battery pointer to a const battery object
 * @param ch      adc channel
 * @param width   adc width
 * @param atten   adc attentuation
 * @param enable  battery gpio
 * @warning Uses ADC1, please @see battery_t
 */
void battery_ctor(battery_t *const battery, adc1_channel_t ch,
                  adc_bits_width_t width, adc_atten_t atten,
                  gpio_num_t enable)
{
    /* Set battery configuration */
    battery->adc_ch = ch;
    battery->width = width;
    battery->attenuation = atten;
    battery->enable = enable;
}

/**
 * @brief Set battery to default configuration
 *
 * @param battery pointer to a const battery object
 * @note  Please @see battery_ctor()
 * @warning Uses ADC1, please @see battery_t
 */
void battery_default(battery_t *const battery)
{
    battery_ctor(battery, ADC_CHANNEL_DEFAULT, ADC_WIDTH_DEFAULT,
                 ADC_ATTENUATION_DEFAULT, BATTERY_ENABLE_DEFAULT);
}

/**
 * @brief Enable battery reading
 *
 * @param battery pointer to const battery object
 */
void battery_enable(battery_t *const battery)
{
    gpio_set_level(battery->enable, 1);
}

/**
 * @brief Disable battery reading
 *
 * @param battery pointer to const battery object
 */
void battery_disable(battery_t *const battery)
{
    gpio_set_level(battery->enable, 0);
}

/**
 * @brief Initialize battery configuration: adc and gpio
 *
 * @param battery   pointer to a const battery object
 * @return esp_err_t status
 * @note    For esp_err_t @see esp_err.h
 * @warning Please use battery_ctor() or battery_default() prior of this function.
 */
esp_err_t battery_init(battery_t *const battery)
{
    /* Check esp-idf version */
#if ESP_IDF_VERSION >= ESP_IDF_VERSION_VAL(5, 0, 0)
    /* Select gpio pad */
    esp_rom_gpio_pad_select_gpio(battery->enable);
#else
    /* Select gpio pad */
    gpio_pad_select_gpio(battery->enable);
#endif
    /* Set gpio direction */
    gpio_set_direction(battery->enable, GPIO_MODE_OUTPUT);
    /* Set gpio low */
    gpio_set_level(battery->enable, 0);

    /* Configure adc1 width*/
    esp_err_t error = adc1_config_width(battery->width);

    /* Check if error */
    if (error != ESP_OK)
    {
        return error;
    }

    /* Configure adc channel attenuation */
    error = adc1_config_channel_atten(battery->adc_ch, battery->attenuation);

    /* Check if error */
    if (error != ESP_OK)
    {
        return error;
    }

    return ESP_OK;
}

/**
 * @brief Get battery voltage reading
 *
 * @param battery pointer to a const battery object
 * @return int    voltage reading
 * @note   reading will be stored in battery.value
 */
int battery_read(battery_t *const battery)
{
    return battery->value = adc1_get_raw(battery->adc_ch);
}

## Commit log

2022-07-23 Update led example with correct gpio function calls
    [blink_example_main.c]
2022-07-24 Added serial monitor to avoid using putty/screen
    [blink_example_main.c, monitor.py]
2022-08-05 Update cmake to build drivers
2022-08-10 Added button.h
2022-08-10 Added button.c
2022-08-10 Update main and cmake to build and use latest drivers
2022-08-16 Changed drivers paths
2022-08-16 Added devices source in cmake
2022-08-16 Update devices path and change cmake
2022-08-17 Fix esp-idf v4.x error
    [main.c]
2022-08-17 Redid led_toggle
2022-08-17 Changed esp_rom_printf to printf
2022-08-20 Added lcd driver
2022-08-20 Added lcd driver to cmake
2022-08-20 Added lcd driver files to devices
2022-08-20 Remove gps driver
2022-08-23 Changed drivers paths to components
2022-08-24 Create new task with esp-idf-lib drivers
2022-08-25 Added esp32 pin selection
2022-08-26 Added new ssd1306 driver as submodule
2022-08-26 Updated cmake to use new driver
2022-08-26 Added submodule drivers to project
2022-08-27 Added rtc driver
2022-08-28 Fix esp-idf spi version
    [main.c]
2022-08-29 Added esp timer task
2022-08-29 Fix %d -> %lu
    [main.c]
2022-09-01 Added battery task
2022-09-01 Added new battery driver
2022-09-01 Edit action workflow for only ESP32
2022-09-03 Changed adc default channel
2022-09-03 Added current schematic: esp32, 3.3v ldo, i2c, analog pins, and rtc
    [Sensor Data Logger.kicad_sch]
2022-09-06 Added schematic
2022-09-06 Latest schematic
    [Sensor Data Logger.kicad_sch, battery_circuit.kicad_sch]
2022-09-06 Update battery adc enable pin
2022-09-07 Latest hardware changes
    [Sensor Data Logger.kicad_pcb, Sensor Data Logger.kicad_sch]
2022-09-07 Added schematic.pdf
2022-09-11 Update latest hardware changes
    [BOM-Sensor Data Logger.csv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]
2022-09-11 Changed path
    [BOM-Sensor Data Logger.csv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]
2022-09-13 Remove stl file
2022-09-21 Added mechanical housing
